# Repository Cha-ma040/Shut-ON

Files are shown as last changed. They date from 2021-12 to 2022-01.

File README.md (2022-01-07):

# Shut音

## 製品の概要
本製品は物件の防音性能を手軽に評価するデバイスになります。

ただし、現段階では未実装部分もあることに注意してください。

また、この製品にはSpresenseのLTE拡張ボードが必要となります。

## ビルド
1.SpresenseのArduinoプロジェクトがビルドできる状態にします(詳細は[SonyのSPRESENSE公式ページ](https://developer.sony.com/develop/spresense/docs/arduino_set_up_ja.html)をご覧ください)。

2.ArudinoIDEでMAinフォルダにあるMain.inoを開いてください。

3.SpresenseをPCに接続します。また、マイクとスピーカーも接続します。

3.1.SDフォルダの中身をSDカードに移し替えて、SDカードをSpresenseに挿してください。

4.Main.inoをSpresenseに書き込みます。

## センサーについて
この製品を扱うにあたって、Spresenseと各センサーの接続は以下の画像を参考にしてください。

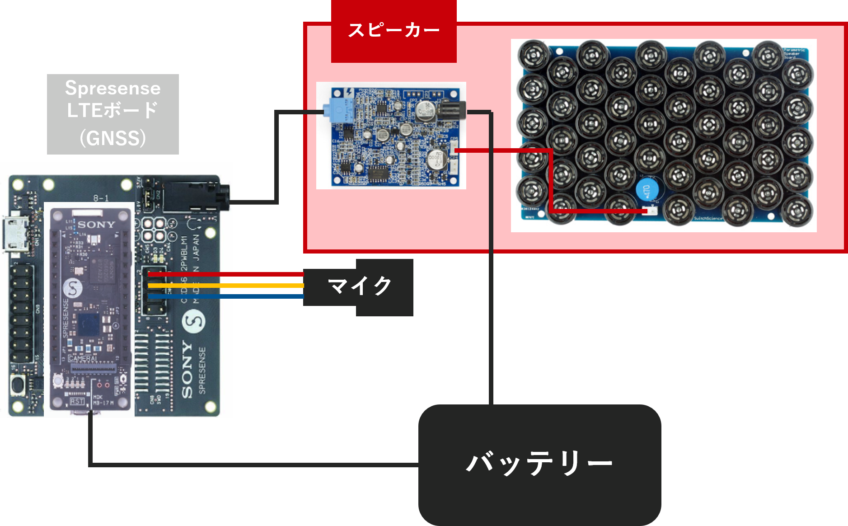
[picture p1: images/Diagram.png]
接続


また、我々が設計した際の仕様書は以下の通りになります。実際に求めるマイクとスピーカー、バッテリーのスペックは何段階か下げても問題ないと思われます。

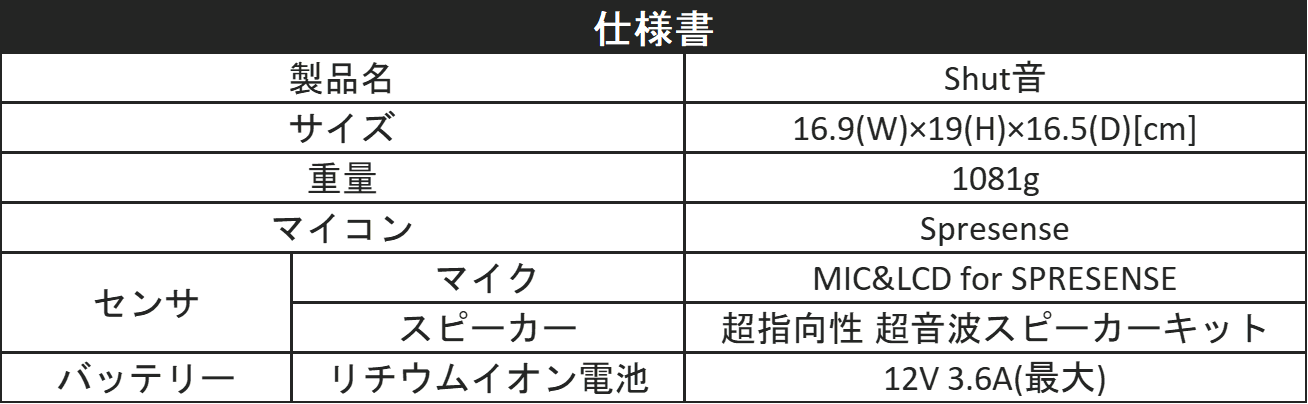
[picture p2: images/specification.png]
仕様


## 使い方(予定)
1.スケッチの書き込み、センサーの接続を終えます。

2.壁に向かって、マイクとスピーカーを向けたら、スイッチをONにします。

3.GPSの座標を取得するために外に出て30秒ほどお待ちください。

4.座標と反響音を取得次第、クラウドへデータを送信し、防音性能の評価を行います。他のデバイスで評価結果をご確認ください。

## クラウド側のシステム・環境要求
- Ubuntu 18.04/20.04
- CPython >= 3.6

## クラウド側のインストール方法と使い方
```bash
bash aws/install.sh # Install requirement packages and modules

cd aws/backend && python3 server.py # Run the server
```

## 機能(予定)
本製品の機能は以下の通りです。

・Spresenseの高い精度のGNSSを用いた座標取得

・スピーカーから壁へ音を照射し、その反響音をマイクで録音

・クラウド側で取得した録音データと基準となる反響音データと比較して、防音性能を評価

・地図上への座標と防音性能を保存

詳しくは以下の動画をご覧ください。

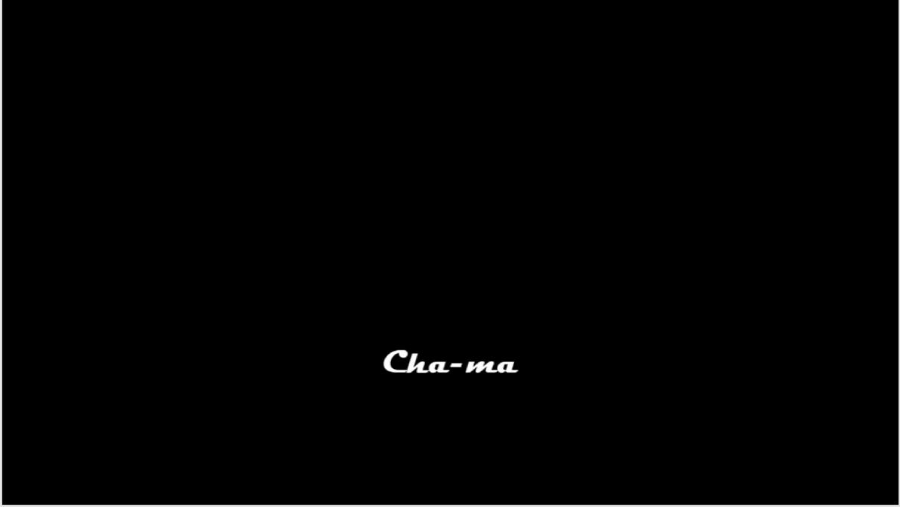
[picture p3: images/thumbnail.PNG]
movie (https://user-images.githubusercontent.com/93237025/148518990-fd2f7766-0817-4d73-b0f5-9052ba7b677b.mp4)


## システムモデル

本製品のシステム構成図のイメージ図は以下の通りです。

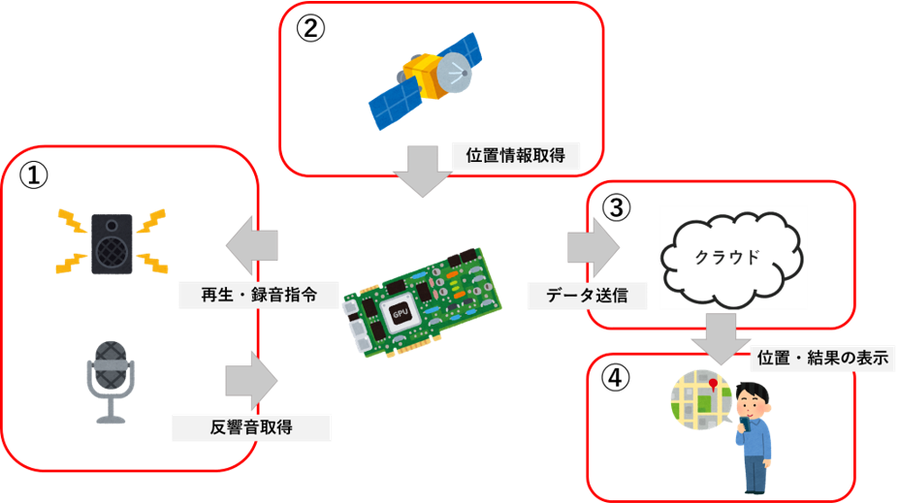
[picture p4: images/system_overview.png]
system


## 実装部分・未実装部分

### 実装部分

録音・再生・位置情報取得・防音性能評価・データ管理

### 未実装部分

クラウドとSpresense間の通信(LTE拡張ボードがないため実装不可)

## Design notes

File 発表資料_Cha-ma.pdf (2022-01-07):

# Shut音

チーム Cha-ma

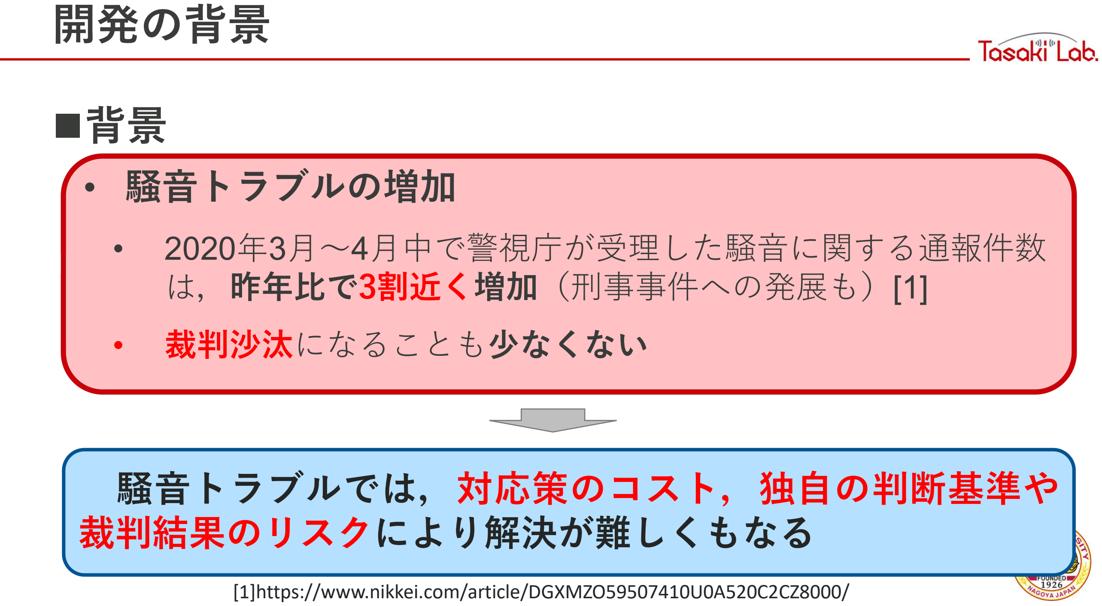
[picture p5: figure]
開発の背景; 背景 • 騒音トラブルの増加; • 2020年3月～4月中で警視庁が受理した騒音に関する通報件数 は，昨年比で3割近く増加（刑事事件への発展も）[1] • 裁判沙汰になることも少なくない; [1]https://www.nikkei.com/article/DGXMZO59507410U0A520C2CZ8000/; 騒音トラブルでは，対応策のコスト，独自の判断基準や 裁判結果のリスクにより解決が難しくもなる

## 騒音トラブル増加の主な原因

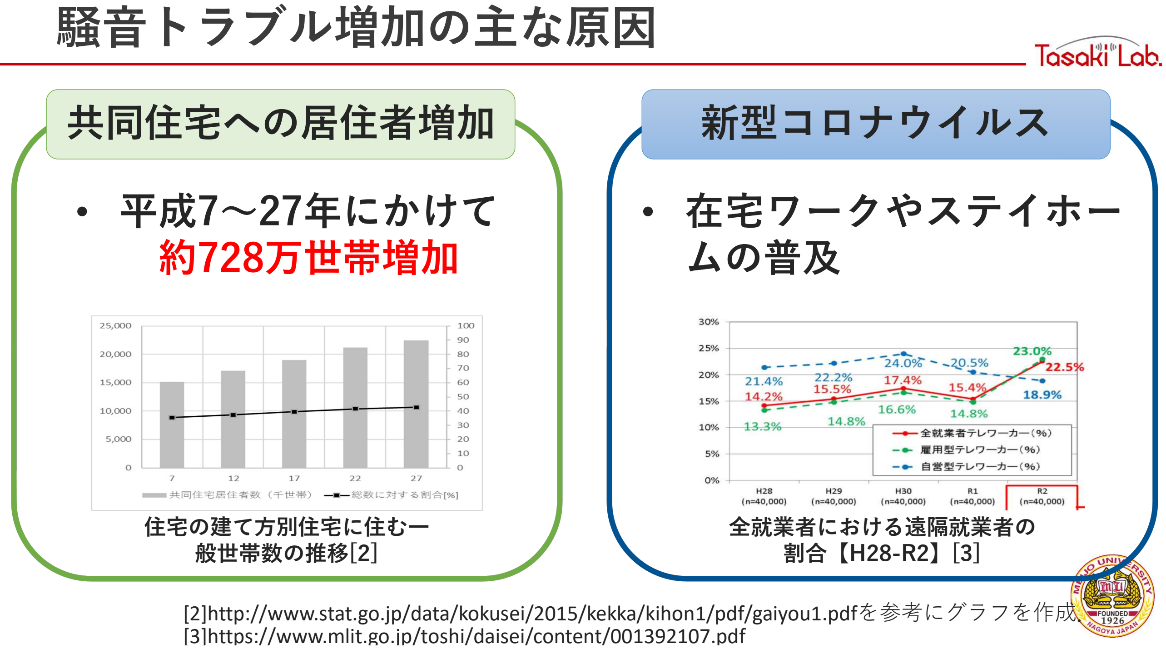
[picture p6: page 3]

[2]http://www.stat.go.jp/data/kokusei/2015/kekka/kihon1/pdf/gaiyou1.pdfを参考にグラフを作成．

住宅の建て方別住宅に住む一
般世帯数の推移[2]
- 平成7～27年にかけて
約728万世帯増加

共同住宅への居住者増加

- 在宅ワークやステイホー
ムの普及

新型コロナウイルス

全就業者における遠隔就業者の
割合【H28-R2】[3]

[3]https://www.mlit.go.jp/toshi/daisei/content/001392107.pdf

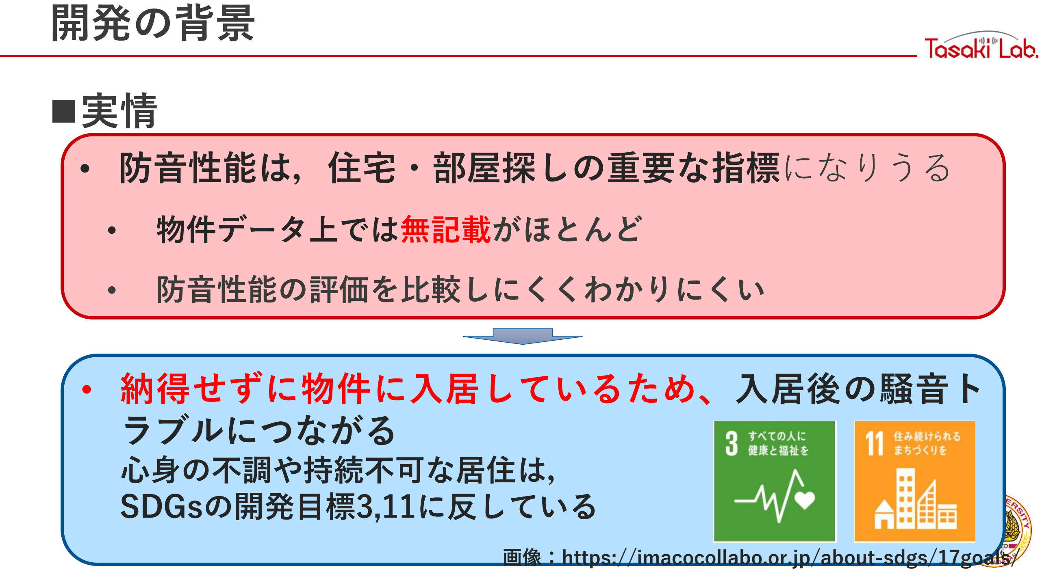
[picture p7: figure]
開発の背景; 実情 • 防音性能は，住宅・部屋探しの重要な指標になりうる; • 物件データ上では無記載がほとんど; • 防音性能の評価を比較しにくくわかりにくい; • 納得せずに物件に入居しているため、入居後の騒音ト ラブルにつながる 心身の不調や持続不可な居住は， SDGsの開発目標3,11に反している; 画像：https://imacocollabo.or.jp/about-sdgs/17goals/

## 従来の防音性能の評価方法

### 2つの部屋や人手や大掛かりな装置が必要 →物件の内見の時には測定困難

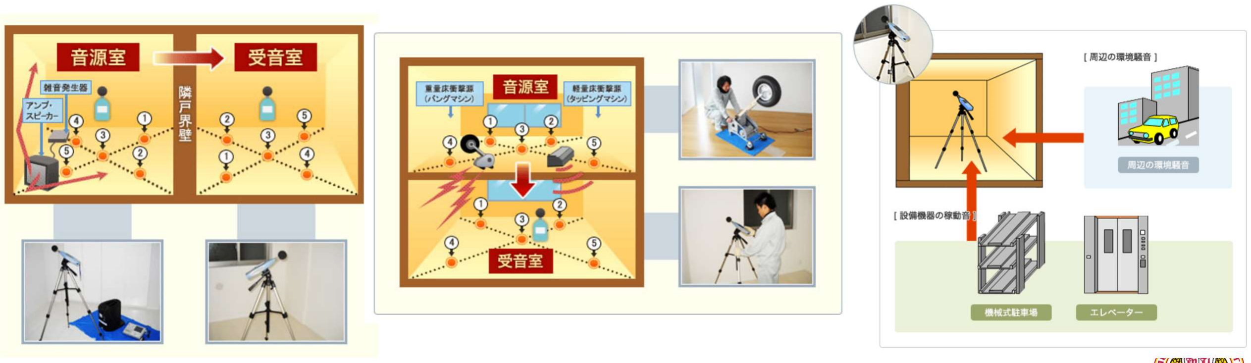
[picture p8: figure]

https://www.kankyo-research.co.jp/noise_and_vibration/measurement.php

目標

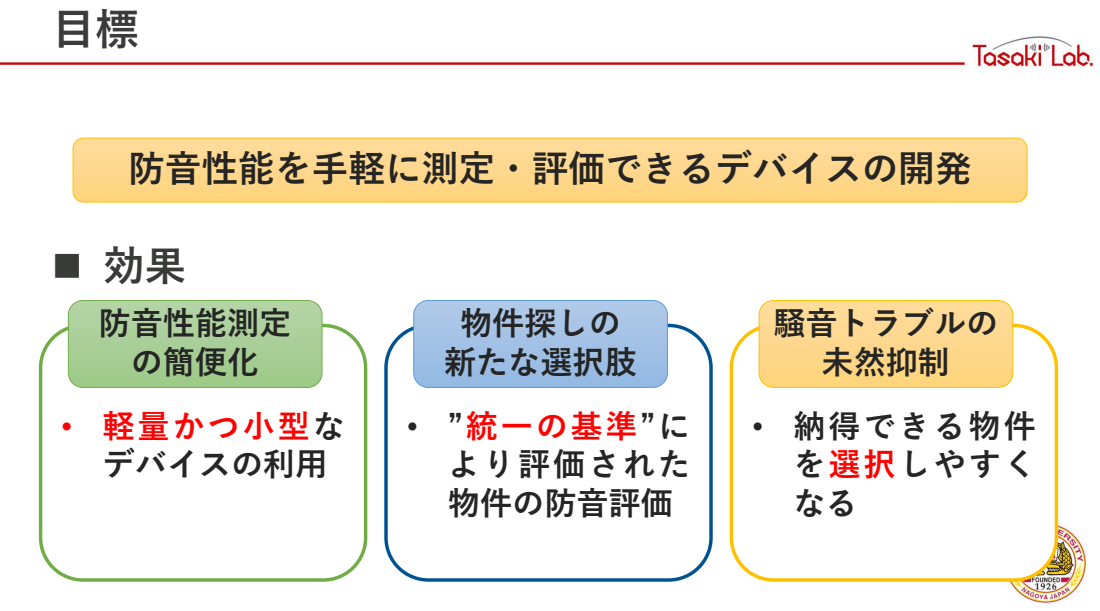
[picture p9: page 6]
防音性能を手軽に測定・評価できるデバイスの開発; • 軽量かつ小型な デバイスの利用; 防音性能測定 の簡便化; ”統一の基準”に より評価された 物件の防音評価; 物件探しの 新たな選択肢; • 納得できる物件 を選択しやすく なる; 騒音トラブルの 未然抑制

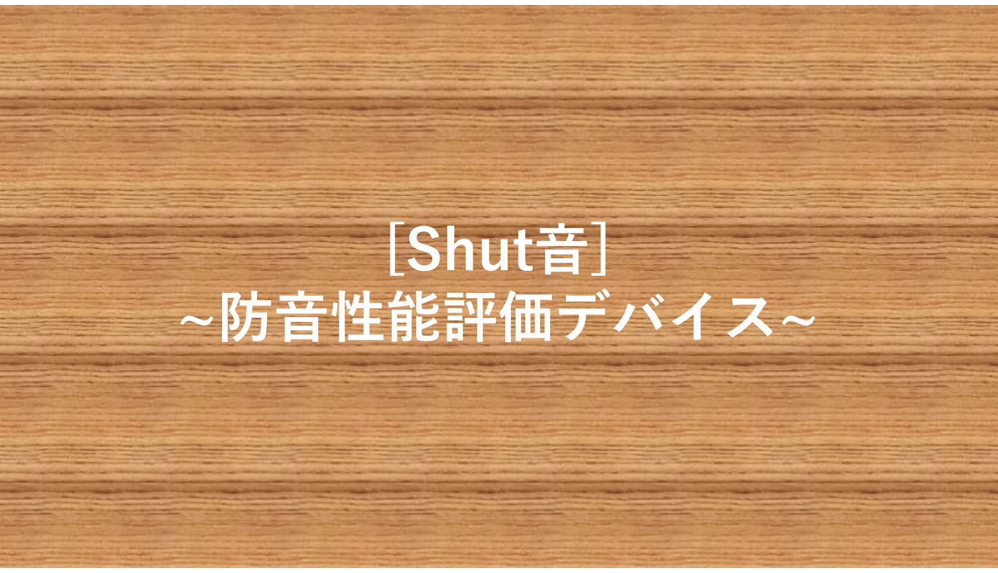
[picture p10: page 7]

# [Shut音] ~防音性能評価デバイス~

## 「Shut音」について

### - デバイスの概要

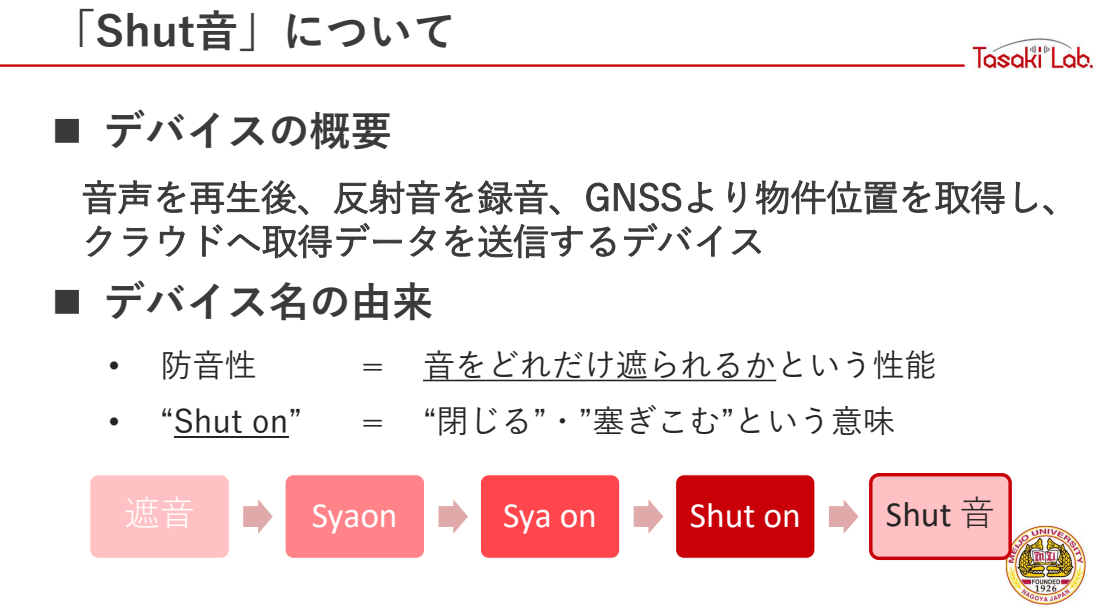
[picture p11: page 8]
• 防音性; = 音をどれだけ遮られるかという性能; • “Shut on”; = “閉じる”・”塞ぎこむ”という意味; Syaon; Sya on; Shut on; Shut 音

音声を再生後、反射音を録音、GNSSより物件位置を取得し、
クラウドへ取得データを送信するデバイス
デバイス名の由来

## システム構成

- 機能
- 再生・録音機能
超音波スピーカの反響音を録音
- 位置情報取得機能
GPS（GNSS）による位置を取得
- クラウド上での防音性能評価・
データ管理
- 他の表示デバイスでの
評価・位置情報の表示

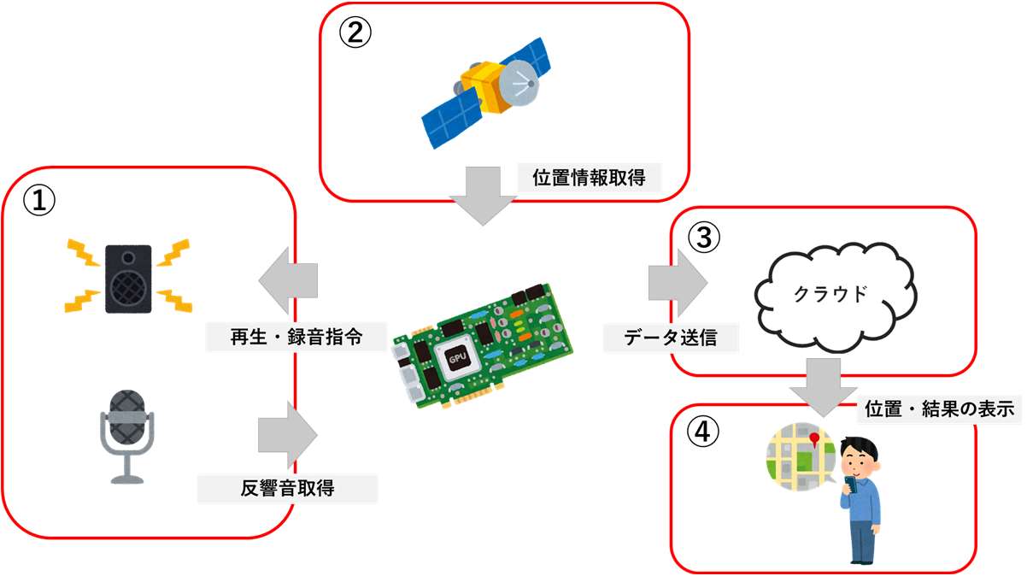
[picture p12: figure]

“Shut音”のシステム構成図

## SPRESENSEの適合性

### - 適合性

- デバイスの小型化による測定の簡便化
- 測定地点の取得では，GNSS機能を用いる
- バッテリを⾧時間持続させることができる低消費電力

## まとめ

目的
- 未然な騒音トラブル防止のために，防音性能を手軽に測定・評 価できるデバイスの開発

### 「Shut音」の概要

- 超音波の反響音を録音しバックエンドに送信することで，PCに 性能評価を表示するデバイス

## 実装完了部分

### Spresense 録音・再生機能

### バックエンド データ受信・管理、防音性能評価、測定位置表示機

能

## 最終完成品

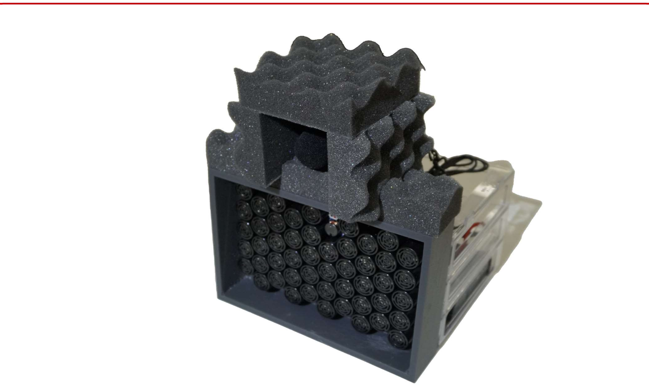
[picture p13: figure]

## 最終完成品

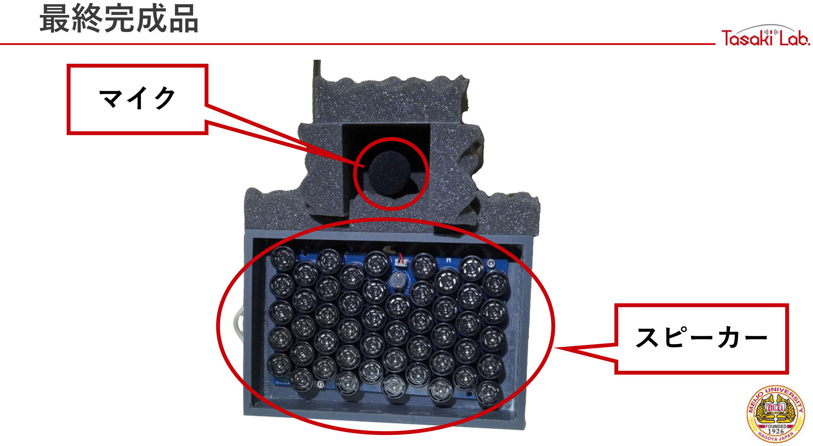
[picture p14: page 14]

マイク

スピーカー

## 最終完成品

### 本体や余計な方向からの音が入らないように吸音材

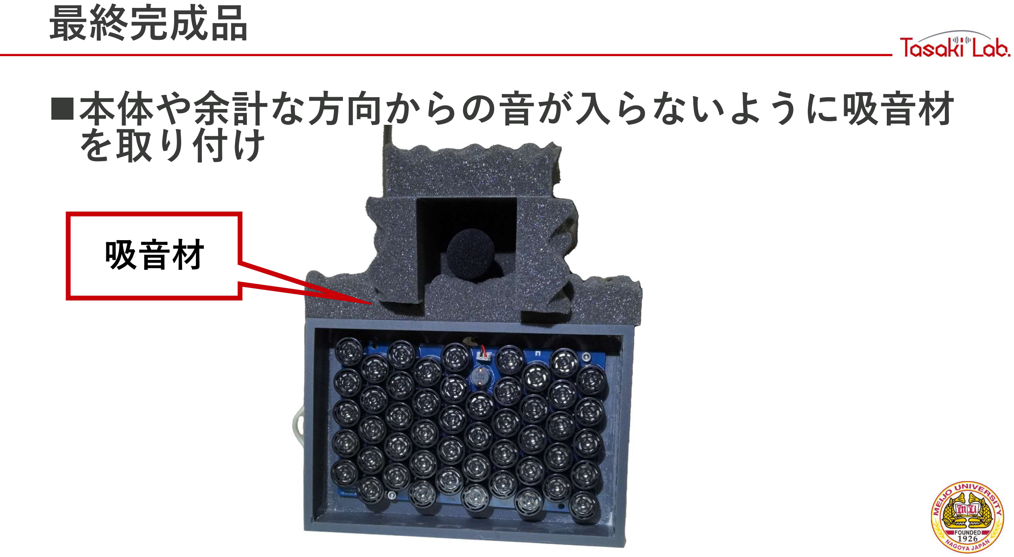
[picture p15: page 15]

吸音材

### を取り付け

## 最終完成品

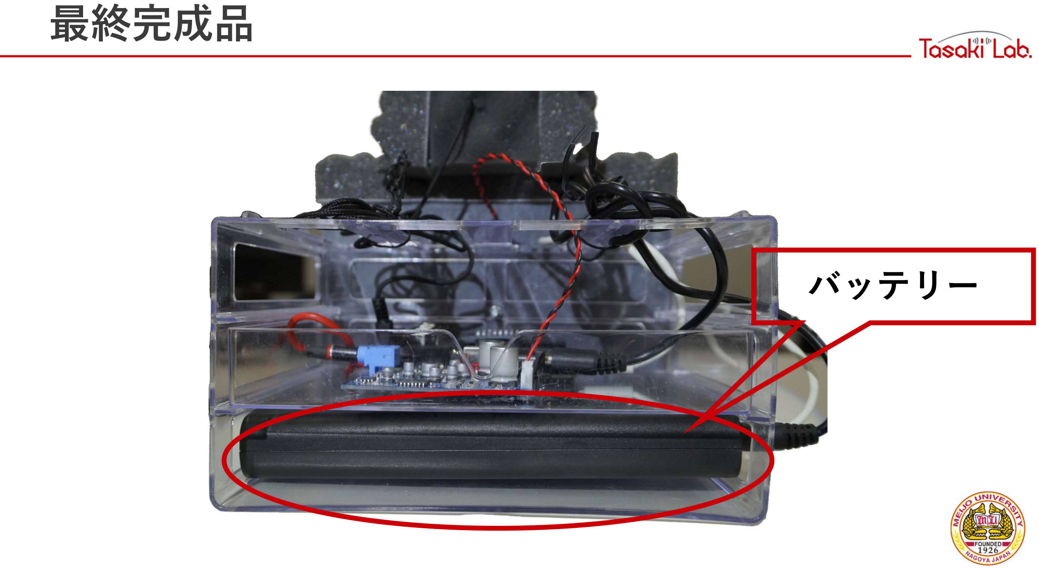
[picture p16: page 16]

バッテリー

## 最終完成品

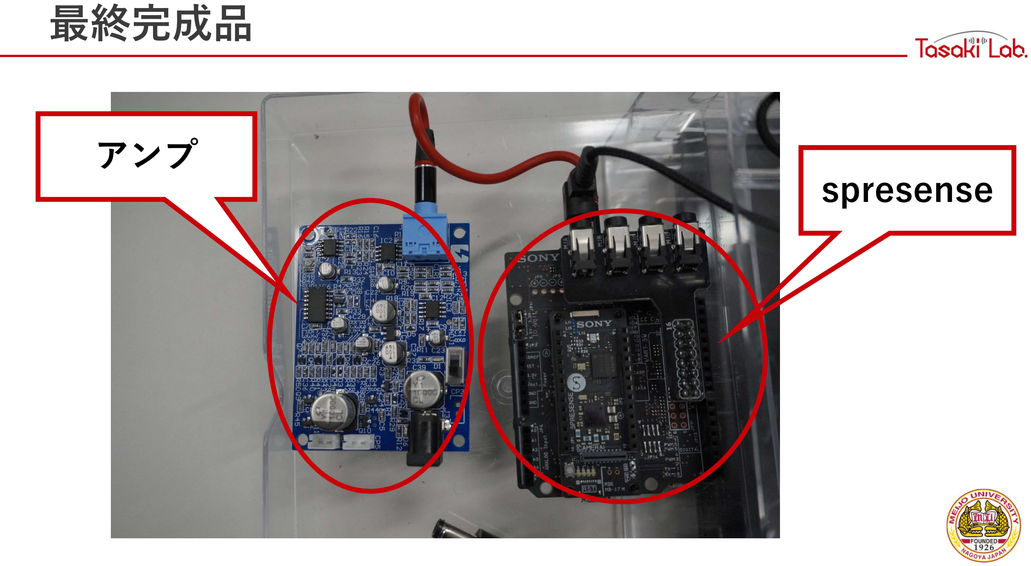
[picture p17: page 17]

spresense

アンプ

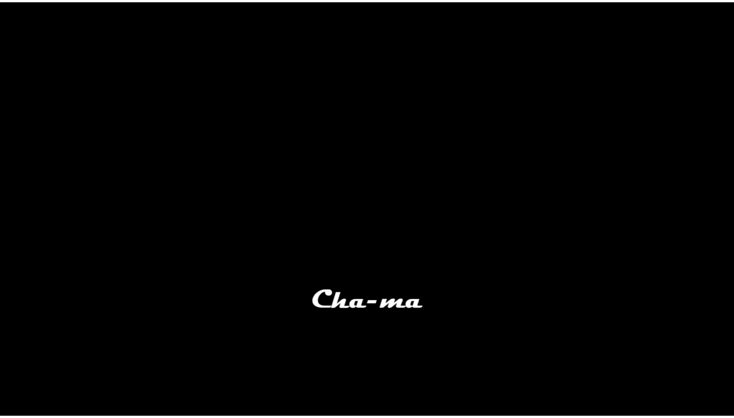
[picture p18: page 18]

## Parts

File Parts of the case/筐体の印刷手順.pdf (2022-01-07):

1. 筐体印刷の準備

1.1 3D プリンタの導入
1.1.1 以下を参考にして，Fusion360 と preform をインストールします．
⚫ | https://www.autodesk.co.jp/campaigns/fusion-360
⚫ | https://i-maker.jp/blog/preform-install-12369.html
1.1.2 Fusion360 を起動します．
1.1.3 [tools]下の[make]から[3D print]をクリックします． 1.1.4 ウィンドウ下部にある[Application]をクリックします． 1.1.5 （ア）の”preform”アプリを選択し，[ok]をクリックします．

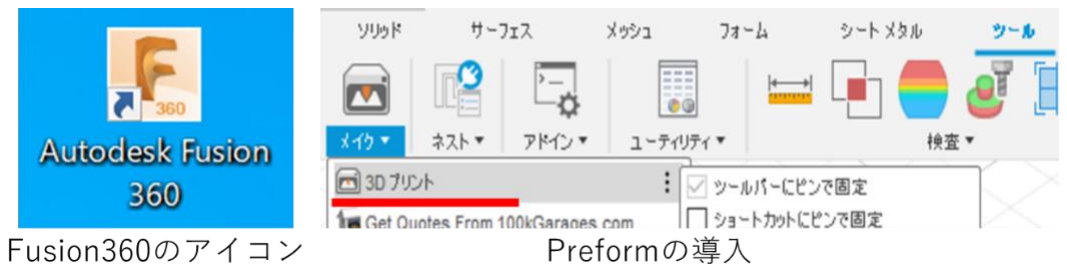
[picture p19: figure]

Fig. 1 3D プリンタの導入 1

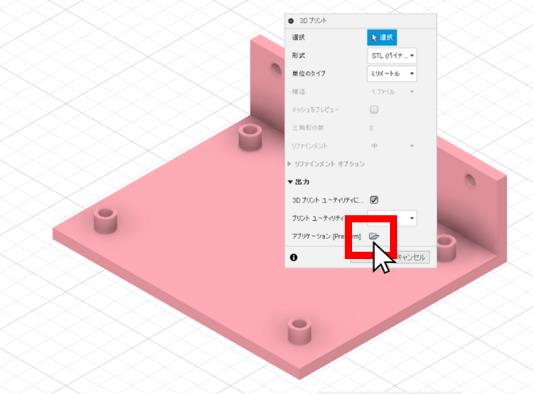
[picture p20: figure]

Fig. 2 3D プリンタの導入 2

1.2 Preform の設定
1.2.1 部品の 3Dcad モデル（stl ファイル）を Fusion360 で開きます． 1.2.2 [tools]下の[make]から[3D print]をクリックします．
1.2.3 部品をクリックし，[ok]をクリックします．
1.2.4 ”preform”が起動します．
1.2.5 以下を参考に，モデルのサイズ，移動や回転，サポート材を設定します．
⚫ | https://support.formlabs.com/s/article/Set-Up-Your-Print?language=ja
1.3 | 筐体の印刷
1.3.1 プリンタの設定で，Tough2000 と光学成形機を選択します。
1.3.2 コンピュータと光造形機を接続し，部品を印刷する．
1.3.3 イソプロピルアルコール（IPA）を含む，特別な form3 /form2 洗浄剤であ る”Form Wash”で部品を 20 分間洗浄します．
1.3.4 Form3/Form2 UV 硬化機”FormCure”で 70°C で 60 分間部品を硬化させます．

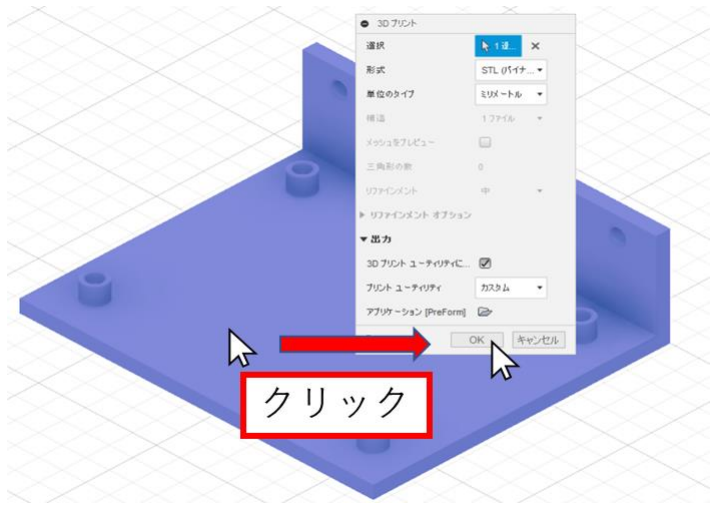
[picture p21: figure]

Fig. 3 preform の設定 1

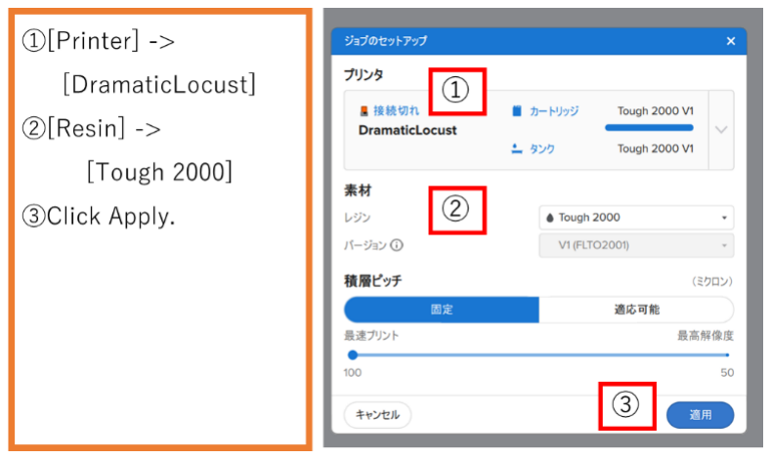
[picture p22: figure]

Fig. 4 preform の設定 2

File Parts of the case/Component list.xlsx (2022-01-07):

 |  | 部品表 |  | グループ名 | 記入日 |  | 記入者名
 |  |  |  | 知能化ロボット学特論 3班 | 2022.01.06 |  | 佐藤
No. | 商品名 |  | 発注先 | 品番 | 販売単価 | 数量 | 小計 | リンク | 備考
1 | Mic&LCD KIT for SPRESENSE |  | Switch Science | AUTOLAB-001 | 6811 | 1 | 6811 | ○ (https://www.switch-science.com/catalog/7155/)
2 | SPRESENSE拡張ボード[CXD5602PWBEXT1] |  | Switch Science | SONY-SPRESENSE-EXT | 3850 | 1 | 3850 | 〇 (https://www.switch-science.com/catalog/3901/) | 録音出音の検証時のみに使用
3 | SPRESENSEメインボード[CXD5602PWBMAIN1] |  | Switch Science | SONY-SPRESENSE-MAIN | 6050 | 2 | 12100 | 〇 (https://www.switch-science.com/catalog/3900/)
4 | SPRESENSE LTE拡張ボード [CXD5602PWBLM1J] |  | Switch Science | SONY-SPRESENSE-LTE | 8778 | 1 | 8778 | 〇 (https://www.switch-science.com/catalog/5999/)
5 | 超指向性 超音波スピーカーキット |  | Switch Science | SSCI-018425 | 22000 | 1 | 22000 | 〇 (https://www.switch-science.com/catalog/1842/)
6 | 吸音パット |  | MonotaRO | WSD005 | 789 | 1 | 789 | 〇 (https://www.monotaro.com/p/4175/2428/)
7 | 3段引出しケース（書斎、クリア） |  | ダイソーネットストア | 商品番号：4549131728576 | 220 | 1 | 220 | 〇 (https://jp.daisonet.com/products/4549131728576?_pos=1&_sid=88366b2a3&_ss=r)
8 | SIMカード |  | 指定なし |  |  |  | 0
9 | microSDHCカード32GB EXTREME PRO |  | MonotaRO | SDSQXCG-032G-GN6MA | 2519 | 1 | 2519 | 〇 (https://www.monotaro.com/g/04324842/)
10 | マイクロUSBケーブル（B Type） |  | 指定なし |  |  |  | 0 |  | 信号通信と電気投入の両方を使用できること
11 | オーディオファン オーディオケーブル 3.5mm 3極 オス ストレート 金メッキ 約13cm (端子含む) レッド |  | Amazon | B07S65TRLK | 418 | 1 | 418 | 〇 (https://www.amazon.co.jp/%E3%82%AA%E3%83%BC%E3%83%87%E3%82%A3%E3%82%AA%E3%83%95%E3%82%A1%E3%83%B3-%E3%82%AA%E3%83%BC%E3%83%87%E3%82%A3%E3%82%AA%E3%82%B1%E3%83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)
12 | バッテリ（リチウムイオン電池） |  | 指定なし |  |  |  | 0 |  | 12V 3.6A（最大）の仕様を満たすこと
13 |  |  |  |  |  |  | 0
14 |  |  |  |  |  |  | 0
15 |  |  |  |  |  |  | 0
16 |  |  |  |  |  |  | 0
17 |  |  |  |  |  |  | 0
18 |  |  |  |  |  |  | 0
19 |  |  |  |  |  |  | 0
20 |  |  |  |  |  |  | 0
 |  |  |  |  |  | 合計 | 57485 | 円

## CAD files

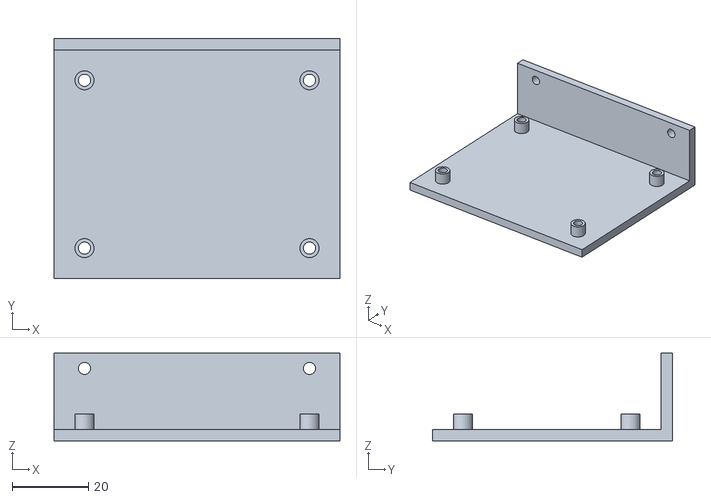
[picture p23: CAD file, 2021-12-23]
Parts of the case/Sony_amp_hole.stl
75.0 x 63.0 x 23.0

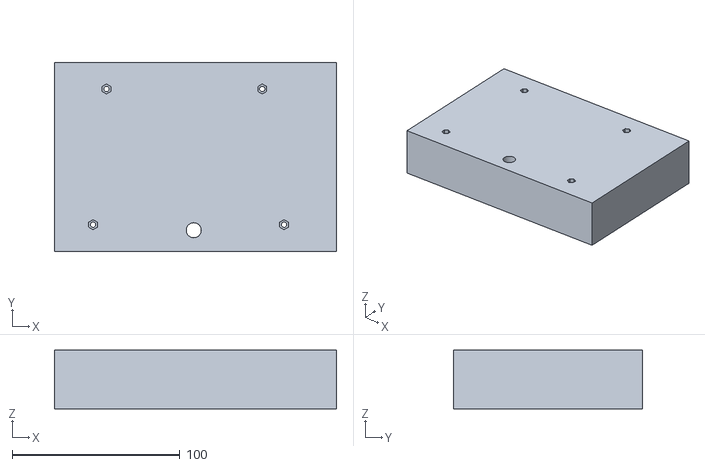
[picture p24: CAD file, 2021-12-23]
Parts of the case/Sony_hackthon_speaker.stl
168.3 x 112.8 x 35.0

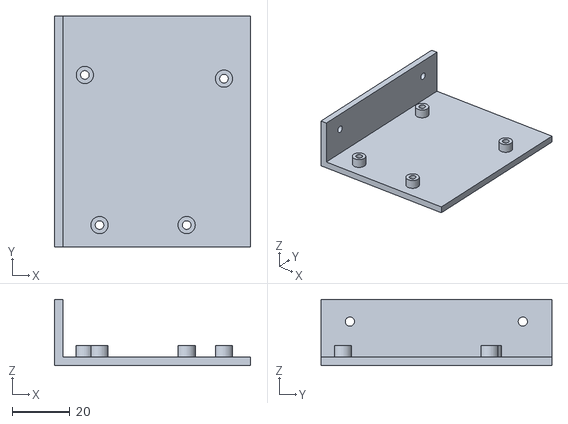
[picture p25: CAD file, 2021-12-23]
Parts of the case/Sony_spresense_hole.stl
68.0 x 80.0 x 23.0

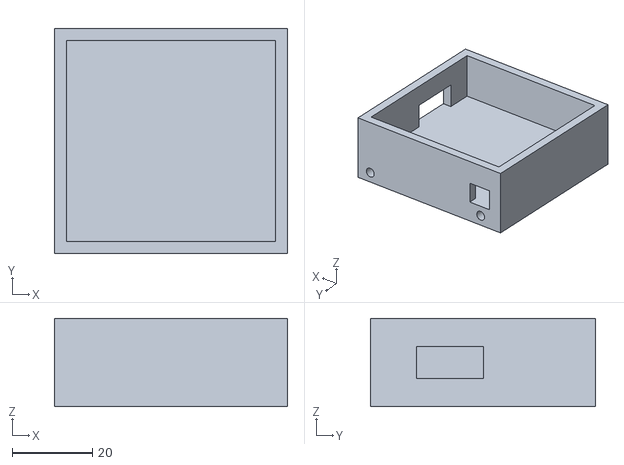
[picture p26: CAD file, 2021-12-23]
Parts of the case/Sony_LTE_hole.stl
58.0 x 56.0 x 22.0

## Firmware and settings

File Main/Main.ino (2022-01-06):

#include <string.h>
#include <SDHCI.h>
#include <MediaRecorder.h>
#include <FrontEnd.h>
#include <MediaPlayer.h>
#include <OutputMixer.h>
#include <MemoryUtil.h>
#include <GNSS.h>

#define RECORD_FILE_NAME "Recorde.wav"
#define ANALOG_MIC_GAIN  0 /* +0dB */
#define STRING_BUFFER_SIZE  128       /**< %Buffer size for GNSS */
#define RESTART_CYCLE       (60 * 5)  /**< positioning test term */
SDClass theSD;

MediaRecorder *theRecorder;
MediaPlayer *thePlayer;
OutputMixer *theMixer;
FrontEnd *theFrontEnd;

File playFile;
File recFile;

bool ErrEnd = false;
bool AudioEnd = false;
bool skip_stoporder = false;

static const uint32_t recoding_sampling_rate = 48000;
static const uint8_t  recoding_cannel_number = 1;
static const uint8_t  recoding_bit_length = 16;
static const uint32_t recoding_time = 1;
static const int32_t recoding_byte_per_second = recoding_sampling_rate *
                                                recoding_cannel_number *
                                                recoding_bit_length / 8;
static const int32_t recoding_size = recoding_byte_per_second * recoding_time;
static const uint32_t frame_size  = 768 * recoding_cannel_number * (recoding_bit_length / 8);
static const uint32_t buffer_size = (frame_size + 511) & ~511;
static uint8_t        s_buffer[2 * buffer_size];

static SpGnss Gnss;

static void attention_cb(const ErrorAttentionParam *atprm)
{
  puts("Attention!");

  if (atprm->error_code >= AS_ATTENTION_CODE_WARNING)
  {
    ErrEnd = true;
  }
}

static void mediarecorder_attention_cb(const ErrorAttentionParam *atprm)
{
  if (atprm->error_code >= AS_ATTENTION_CODE_WARNING)
  {
    ErrEnd = true;
  }
}

static void outputmixer_done_callback(MsgQueId requester_dtq,
                                      MsgType reply_of,
                                      AsOutputMixDoneParam *done_param)
{
  return;
}

static void outmixer_send_callback(int32_t identifier, bool is_end)
{
  AsRequestNextParam next;
  next.type = (!is_end) ? AsNextNormalRequest : AsNextStopResRequest;
  AS_RequestNextPlayerProcess(AS_PLAYER_ID_0, &next);
  return;
}

static bool mediaplayer_done_callback(AsPlayerEvent event, uint32_t result, uint32_t sub_result)
{
  return true;
}

void mediaplayer_decode_callback(AsPcmDataParam pcm_param)
{
  theMixer->sendData(OutputMixer0,
                     outmixer_send_callback,
                     pcm_param);
}

static bool mediarecorder_done_callback(AsRecorderEvent event, uint32_t result, uint32_t sub_result)
{
  UNUSED(event);
  UNUSED(result);
  UNUSED(sub_result);
  return true;
}


void setup()
{
  int error_flag = 0;
  Serial.begin(115200);
  while (!theSD.begin()) {};
  Gnss.setDebugMode(PrintInfo);

  /* start GNSS system */
  int result;
  result = Gnss.begin();
  if (result != 0) {
    puts("Gnss begin error!!");
    error_flag = 1;
  } else {
    Gnss.select(GPS);
    Gnss.select(QZ_L1CA);
    /* Start positioning */
    result = Gnss.start(COLD_START);
    if (result != 0) {
      puts("Gnss start error!!"); error_flag = 1;
    } else {
      puts("Gnss setup OK");
    }
  }
  if (error_flag == 1) {
    exit(0);
  }
  
  initMemoryPools();
  createStaticPools(MEM_LAYOUT_RECORDINGPLAYER);

  /* start audio system */
  thePlayer = MediaPlayer::getInstance();
  theMixer  = OutputMixer::getInstance();
  theRecorder = MediaRecorder::getInstance();

  thePlayer->begin();
  theMixer->begin();
  theRecorder->begin(mediarecorder_attention_cb);

  puts("initialization Audio Library");

  thePlayer->create(MediaPlayer::Player0, attention_cb);
  theMixer->create(attention_cb);

  /* Set rendering clock */
  theMixer->setRenderingClkMode(OUTPUTMIXER_RNDCLK_NORMAL);
  theRecorder->setCapturingClkMode(MEDIARECORDER_CAPCLK_NORMAL);

  /* Activate Player Object */
  thePlayer->activate(MediaPlayer::Player0, mediaplayer_done_callback);
  theMixer->activate(OutputMixer0, HPOutputDevice, outputmixer_done_callback);
  theRecorder->activate(AS_SETRECDR_STS_INPUTDEVICE_MIC, mediarecorder_done_callback);

  usleep(100 * 1000);

  thePlayer->init(MediaPlayer::Player0, AS_CODECTYPE_MP3, "/mnt/sd0/BIN", AS_SAMPLINGRATE_44100, AS_CHANNEL_STEREO);
  theRecorder->init(AS_CODECTYPE_WAV,
                    recoding_cannel_number,
                    recoding_sampling_rate,
                    recoding_bit_length,
                    AS_BITRATE_8000,
                    "/mnt/sd0/BIN");

  while (!theSD.begin()) {
    puts("Insert SD card.");
  }
  if (theSD.exists(RECORD_FILE_NAME)){
      printf("Remove existing file [%s].\n", RECORD_FILE_NAME);
      theSD.remove(RECORD_FILE_NAME);
  }
  playFile = theSD.open("AUDIO/Sound.mp3");
  recFile  = theSD.open(RECORD_FILE_NAME, FILE_WRITE);

  /* Verify file open */
  if (!playFile)
  {
    puts("File open error\n");
    exit(1);
  }
  puts("Open!  recFile\n");

  /* Verify file open */
  if (!recFile)
  {
    puts("File open error\n");
    exit(1);
  }
  puts("Open! recFile\n");

  /* Send first frames to be decoded */
  err_t err = thePlayer->writeFrames(MediaPlayer::Player0, playFile);

  if (err != MEDIAPLAYER_ECODE_OK)
  {
    puts("File Read Error! = ");  Serial.println(String(err));
    playFile.close();
    exit(1);
  }

  puts("Play!");

  usleep(1000);
  /* Main volume set to -16.0 dB, Main player and sub player set to 0 dB */
  theMixer->setVolume(-100, 0, 0);

  theRecorder->writeWavHeader(recFile);
  puts("Update Header!");

  // Start Player
  thePlayer->start(MediaPlayer::Player0, mediaplayer_decode_callback);

  /* Set Gain */
  theRecorder->setMicGain(ANALOG_MIC_GAIN);

  /* Start Recorder */
  theRecorder->start();
}

err_t execute_aframe(uint32_t* size)
{
  err_t err = theRecorder->readFrames(s_buffer, buffer_size, size);

  if (((err == MEDIARECORDER_ECODE_OK) || (err == MEDIARECORDER_ECODE_INSUFFICIENT_BUFFER_AREA)) && (*size > 0))
  {
  } else {
    return err;
  }
  int ret = recFile.write((uint8_t*)&s_buffer, *size);
  if (ret < 0)
  {
    puts("File write error.");
    err = MEDIARECORDER_ECODE_FILEACCESS_ERROR;
  }

  return err;
}

void execute_frames()
{
  uint32_t read_size = 0;
  do
  {
    err_t err = execute_aframe(&read_size);
    if ((err != MEDIARECORDER_ECODE_OK)
        && (err != MEDIARECORDER_ECODE_INSUFFICIENT_BUFFER_AREA))
    {
      break;
    }
  }
  while (read_size > 0);
}

static void print_pos(SpNavData *pNavData)
{
  char StringBuffer[STRING_BUFFER_SIZE];

  /* print time */
  snprintf(StringBuffer, STRING_BUFFER_SIZE, "%04d/%02d/%02d ", pNavData->time.year, pNavData->time.month, pNavData->time.day);
  Serial.print(StringBuffer);

  snprintf(StringBuffer, STRING_BUFFER_SIZE, "%02d:%02d:%02d.%06ld, ", pNavData->time.hour, pNavData->time.minute, pNavData->time.sec, pNavData->time.usec);
  Serial.print(StringBuffer);

  /* print satellites count */
  snprintf(StringBuffer, STRING_BUFFER_SIZE, "numSat:%2d, ", pNavData->numSatellites);
  Serial.print(StringBuffer);

  /* print position data */
  if (pNavData->posFixMode == FixInvalid) {
    puts("No-Fix, ");
  } else {
    puts("Fix, ");
  }
  if (pNavData->posDataExist == 0) {
    puts("No Position");
  } else {
    puts("Lat=");
    Serial.print(pNavData->latitude, 6);
    puts(", Lon=");
    Serial.print(pNavData->longitude, 6);
  }
}

static void print_condition(SpNavData *pNavData)
{
  char StringBuffer[STRING_BUFFER_SIZE];
  unsigned long cnt;

  /* Print satellite count. */
  snprintf(StringBuffer, STRING_BUFFER_SIZE, "numSatellites:%2d\n", pNavData->numSatellites);
  Serial.print(StringBuffer);

  for (cnt = 0; cnt < pNavData->numSatellites; cnt++) {
    const char *pType = "---";
    SpSatelliteType sattype = pNavData->getSatelliteType(cnt);
    switch (sattype) {
      case GPS:
        pType = "GPS";
        break;
      case QZ_L1CA:
        pType = "QCA";
        break;
      default:
        pType = "UKN";
        break;
    }

    /* Get print conditions. */
    unsigned long Id  = pNavData->getSatelliteId(cnt);
    unsigned long Elv = pNavData->getSatelliteElevation(cnt);
    unsigned long Azm = pNavData->getSatelliteAzimuth(cnt);
    float sigLevel = pNavData->getSatelliteSignalLevel(cnt);

    /* Print satellite condition. */
    snprintf(StringBuffer, STRING_BUFFER_SIZE, "[%2ld] Type:%s, Id:%2ld, Elv:%2ld, Azm:%3ld, CN0:", cnt, pType, Id, Elv, Azm );
    Serial.print(StringBuffer);
    Serial.println(sigLevel, 6);
  }
}

void loop()
{
  static int32_t total_size = 0;
  uint32_t read_size = 0;
  err_t err;

  if(AudioEnd){
    skip_stoporder = true;
    goto stop_player;
  }

#if 1
  /* Execute audio data */
  if(!AudioEnd){
    err = execute_aframe(&read_size);
    if (err != MEDIARECORDER_ECODE_OK && err != MEDIARECORDER_ECODE_INSUFFICIENT_BUFFER_AREA)
    {
      puts("Recording Error!");
      AudioEnd = true;
      goto stop_player;
    }
    else if (read_size > 0)
    {
      total_size += read_size;
    }
  
    /* Stop Recording */
    if (total_size > recoding_size)
    {
      AudioEnd = true;
      goto stop_player;
    }
  }
#endif

  /* Send new frames to decode in a loop until file ends */
  if(!AudioEnd){
    err = thePlayer->writeFrames(MediaPlayer::Player0, playFile);
  }
#if 0
  if(!AudioEnd){
    /*  Tell when player file ends */
    if (err == MEDIAPLAYER_ECODE_FILEEND)
    {
      puts("Main player File End!\n");
    }
  
    /* Show error code from player and stop */
    if (err)
    {
      puts("Main player error code: ");  Serial.println(String(err));
      AudioEnd = true;
      goto stop_player;
      
    }
  
    if (ErrEnd)
    {
      puts("Error End\n");
      AudioEnd = true;
      goto stop_player;
    }
  }
#endif

  /* Don't go further and continue play */
  return;

stop_player:
  if(!skip_stoporder){
    theRecorder->stop();
    thePlayer->stop(MediaPlayer::Player0);
    execute_frames();
    theRecorder->writeWavHeader(recFile);
    puts("Update Header!");
  
    /* Get ramaining data(flushing) */
    sleep(1); /* For data pipline stop */
    playFile.close();
    recFile.close();
  
    thePlayer->deactivate(MediaPlayer::Player0);
    theRecorder->deactivate();
    thePlayer->end();
    theRecorder->end();
    puts("End Recording");
  }

  static int LastPrintMin = 0;

  /* Check update. */
  if (Gnss.waitUpdate(-1))
  {
    /* Get NaviData. */
    SpNavData NavData;
    Gnss.getNavData(&NavData);

    /* Set posfix LED. */
    bool LedSet = (NavData.posDataExist && (NavData.posFixMode != FixInvalid));
    /* Print satellite information every minute. */
    if (NavData.time.minute != LastPrintMin){
      print_condition(&NavData);
      LastPrintMin = NavData.time.minute;
    }
    print_pos(&NavData);
  }else{
    puts("data not update");
  }

}

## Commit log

2021-10-29 We changed the sample code -- Beep sound output -- into the code that has loop of Beep sound with spresense.
2021-11-23 put samples in wave_sample
2021-11-24 [add] aws用のファイルを追加
2021-11-24 [add] aws起動時にインストールする用のファイルの追加
2021-11-24 [change] 通信するためのポート番号の変更
2021-11-24 [modify] 必要なライブラリの追加
2021-12-18 [add] 防音評価用のプログラムの追加
2021-12-18 [change] 防音性能に必要なライブラリの追加
